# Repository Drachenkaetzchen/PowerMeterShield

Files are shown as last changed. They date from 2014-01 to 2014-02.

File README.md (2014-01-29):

#### **Voltage and Current Meter Shield**

This is a shield to measure voltage (±30V) and current (±10A). It is isolated, so you can hook it up either polarity and even measure negative voltages.

#### **Usage Ideas**
- Combine this shield with an SD card shield to create a data-logging multimeter.
- Combine this shield with a WiFi-Shield to log data to the internet.
- Use the WiFi shield with a solar panel to measure how much power you harvest
- Measure the power consumption of your QuadCopter during flight

#### **Theory of Operation**

Voltage is measured using the THS4521 differential amplifier by converting a bipolar single-ended voltage into a differential voltage, which is fed into the ADC.

Current is measured via the 5mΩ shunt resistor and amplified using the INA170 high-side current shunt monitor. It is converted into a voltage and fed into the ADC.  A 1.024V reference is used to level shift the signal for the ADC so that we can measure negative currents as well (negative range: 0-1.024V and positive range 1.024V to 2.048V).

The ADC used is a MCP3426, which supports up to 16 bits of resolution and an integrated gain amplifier (1x, 2x, 4x and 8x), so if you don't need the full input range of ±30V, you can measure smaller voltages with higher resolutions. The ADC is controlled via I²C.

The ADUM1250 isolates the I²C communications and a 5V DC to DC converter isolates the power rails for the shield.

#### **Specifications**
- Voltage Measurements from -30V to +30V
- Current Measurement from -10A to +10A
- Resolution is 12, 14 or 16 bits. This affects the sample rate (Samples per Second or SPS). 15 SPS at 16 Bits, 60 SPS at 14 Bits and 240 SPS at 12 Bits.
- Digital Gain control of 1x, 2x, 4x or 8x gain
- Input Impedance: >10MΩ
- Burden Voltage: 5mV/A
- Resolution for Voltage Measurements at 16 bit: 4mV at 1x gain (±30V), 2mV at 2x gain (±15V), 1mV at 4x gain (±7.5V) and 0.5mV at 8x gain (±3.75V)
- Resolution for Current Measurements at 16 bit: 1.2mA at 1x gain (±10A), 0.6mA at 2x gain (±5A), 0.3mA at 4x gain (±2.5A) and 0.15mA at 8x gain (±1.25A)
- Works out of the box with all Arduino platforms that feature VREF, SDA and SCL pins. For older Arduino platforms, you may wire VREF to +5V and SDA/SCL to A4/A5 pins.

#### **Project History**

I have built a [solar powered router](http://felicitus.org/solarwind/) for which I have designed a voltage and current measurement board. The voltage and current meter shield evolved from that monitoring board.

I have taken great care to make this shield relatively safe; it doesn't matter which way you connect the measurement inputs - your Arduino will survive due to the isolation (unless you exceed the specified ±30V ±10A input ranges).

#### **License**

This board is licensed under the CERN OHL v1.2.

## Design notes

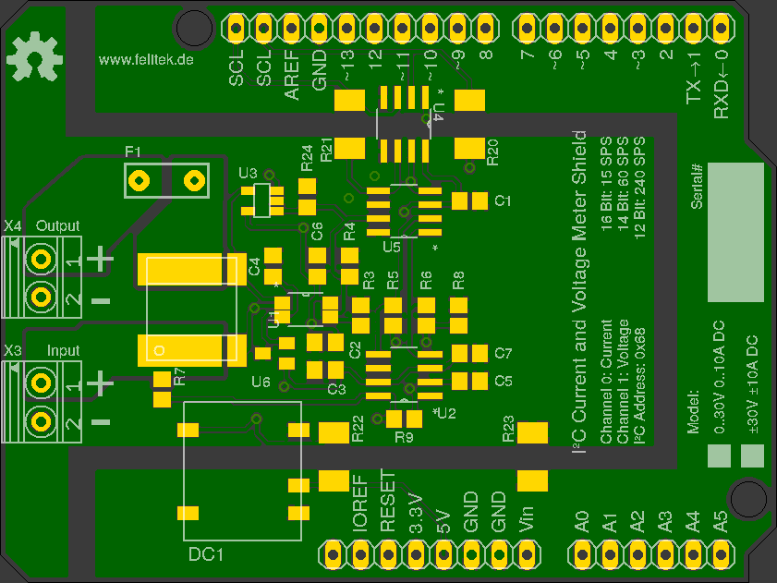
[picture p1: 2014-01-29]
PowerMeterShield_top.png

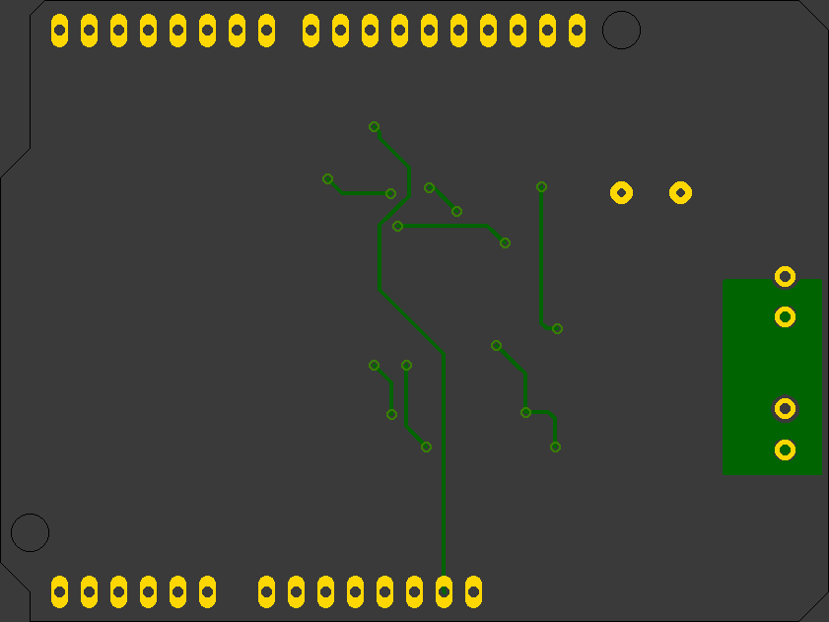
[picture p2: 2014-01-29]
PowerMeterShield_bot.png

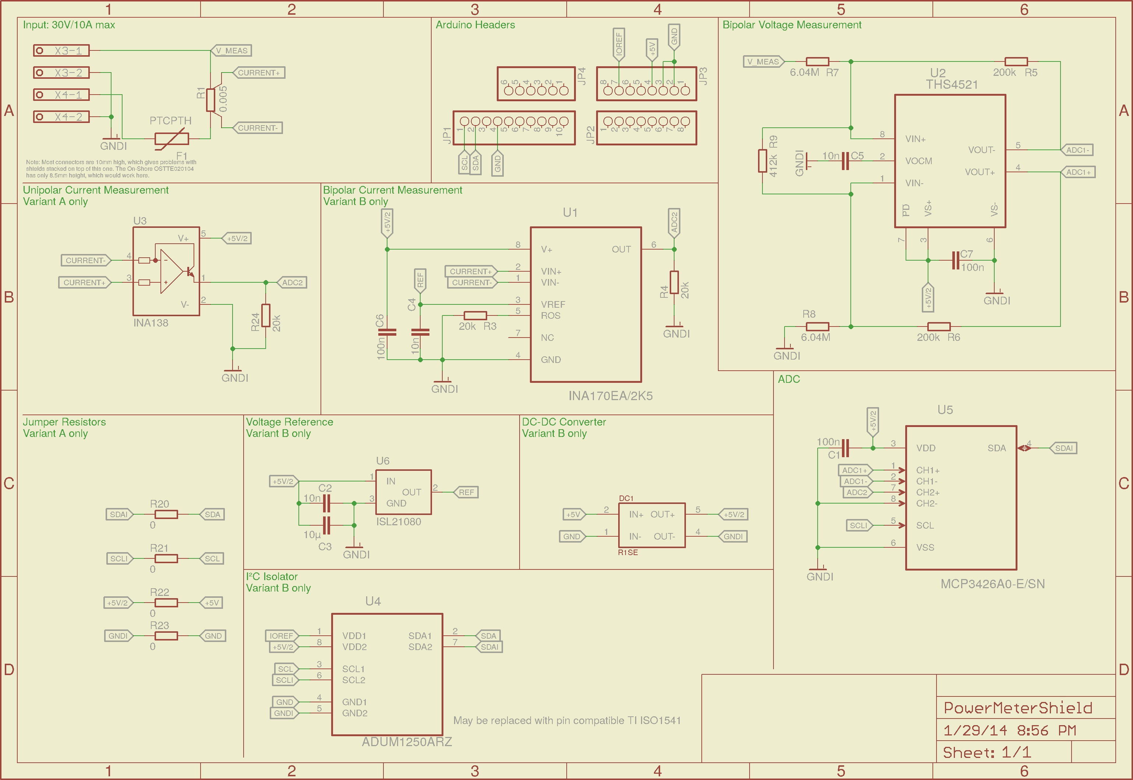
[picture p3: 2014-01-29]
PowerMeterShield_sheet1.png

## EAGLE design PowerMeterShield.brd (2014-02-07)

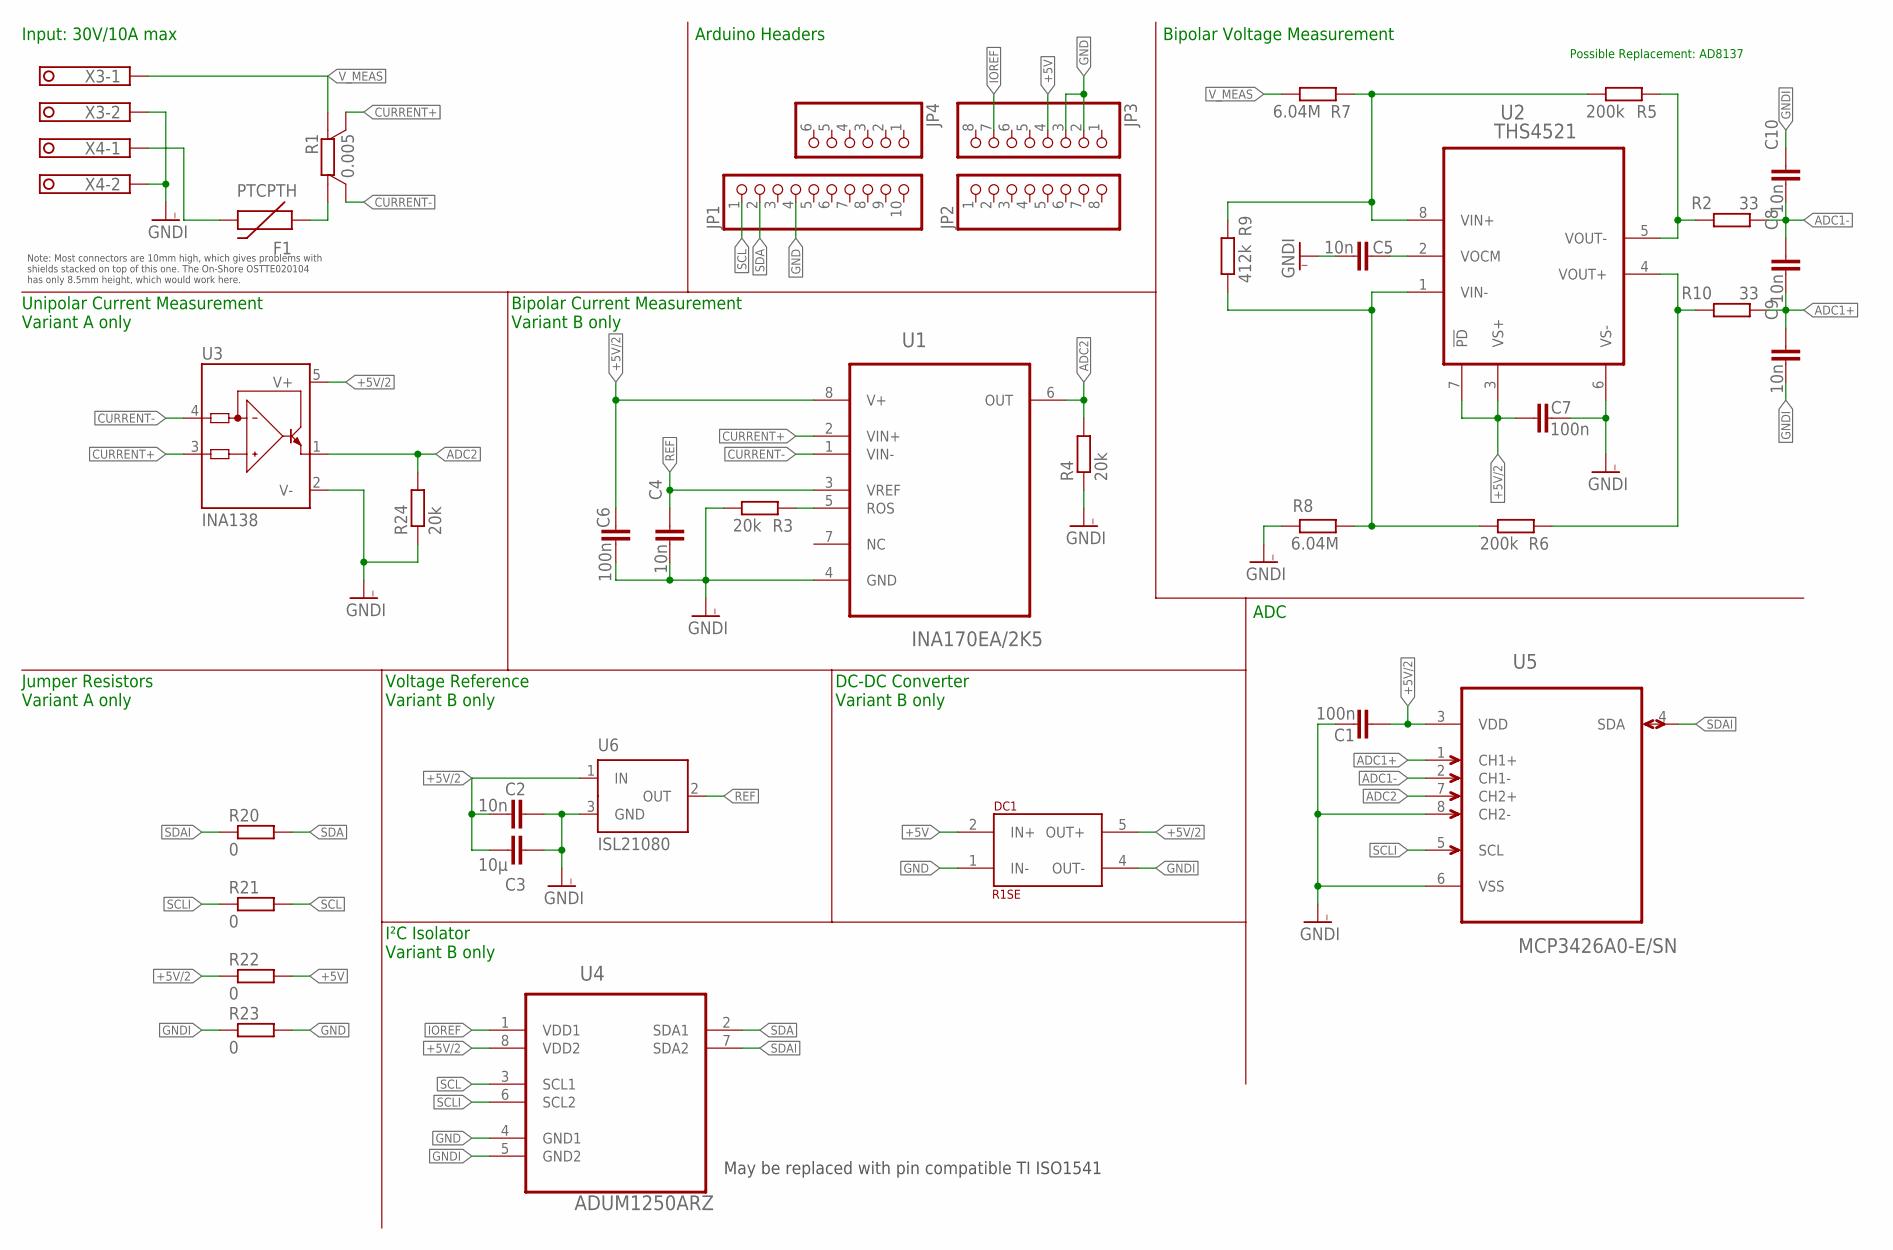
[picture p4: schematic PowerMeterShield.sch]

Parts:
C1, C6, C7: 100n; C0805
C2, C4, C5, C8, C9, C10: 10n; C0805
C3: 10µ; C0805
DC1: R1SE
F1: PTCPTH; PTC
JP1: PINHD-1X10; 1X10
JP2, JP3: PINHD-1X8; 1X08
JP4: PINHD-1X6; 1X06
R1: 0.005; CSM3637M
R2, R10: 33; R0805
R3, R4, R24: 20k; R0805
R5, R6: 200k; R0805
R7, R8: 6.04M; R0805
R9: 412k; R0805
R20, R21, R22, R23: 0; R2010
U1: INA170EA/2K5; SOP65P490X110-8N
U2: THS4521; SOIC127P600X175-8N
U3: INA138; SOT23-5
U4: ADUM1250ARZ; SOIC127P600X175-8N
U5: MCP3426A0-E/SN; SOIC127P600X175-8N
U6: ISL21080; SOT23
X3, X4: 1751248

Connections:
+5V: DC1.2 (IN+), JP3.4, R22.2
+5V/2: C1.1, C2.1, C3.1, C6.1, C7.1, DC1.5 (OUT+), R22.1, U1.8 (V+), U2.3 (VS+), U2.7 (!PD), U3.5 (V+), U4.8 (VDD2), U5.3 (VDD), U6.1 (IN)
ADC1+: C8.1, C9.2, R10.1, U5.1 (CH1+)
ADC1+_OLD: R6.2, R10.2, U2.4 (VOUT+)
ADC1-: C8.2, C10.1, R2.1, U5.2 (CH1-)
ADC1-_OLD: R2.2, R5.2, U2.5 (VOUT-)
ADC2: R4.2, R24.2, U1.6 (OUT), U3.1 (OUT), U5.7 (CH2+)
CURRENT+: R1.S2, U1.2 (VIN+), U3.3 (IN+)
CURRENT-: R1.S1, U1.1 (VIN-), U3.4 (IN-)
GND: DC1.1 (IN-), JP1.4, JP3.2, JP3.3, R23.2, U4.4 (GND1)
GNDI: C1.2, C2.2, C3.2, C4.1, C5.1, C6.2, C7.2, C9.1, C10.2, DC1.4 (OUT-), R3.1, R4.1, R8.1, R23.1, R24.1, U1.4 (GND), U2.6 (VS-), U3.2 (V-), U4.5 (GND2), U5.6 (VSS), U5.8 (CH2-), U6.3 (GND), X3.2, X4.2
IOREF: JP3.7, U4.1 (VDD1)
unnamed: C5.2, U2.2 (VOCM)
unnamed: R5.1, R7.2, R9.2, U2.8 (VIN+)
unnamed: F1.P$1 (1), R1.I1
unnamed: R3.2, U1.5 (ROS)
unnamed: R6.1, R8.2, R9.1, U2.1 (VIN-)
REF: C4.2, U1.3 (VREF), U6.2 (OUT)
SCL: JP1.1, R21.2, U4.3 (SCL1)
SCLI: R21.1, U4.6 (SCL2), U5.5 (SCL)
SDA: JP1.2, R20.2, U4.2 (SDA1)
SDAI: R20.1, U4.7 (SDA2), U5.4 (SDA)
VIN_MEAS: F1.P$2 (2), X4.1
V_MEAS: R1.I2, R7.1, X3.1

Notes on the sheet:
Input: 30V/10A max
Voltage Reference Variant B only
DC-DC Converter Variant B only
Arduino Headers
ADC
I²C Isolator Variant B only
Bipolar Voltage Measurement
Bipolar Current Measurement Variant B only
Unipolar Current Measurement Variant A only
Jumper Resistors Variant A only
Note: Most connectors are 10mm high, which gives problems with shields stacked on top of this one. The On-Shore OSTTE020104 has only 8.5mm height, which would work here.
May be replaced with pin compatible TI ISO1541
Possible Replacement: AD8137

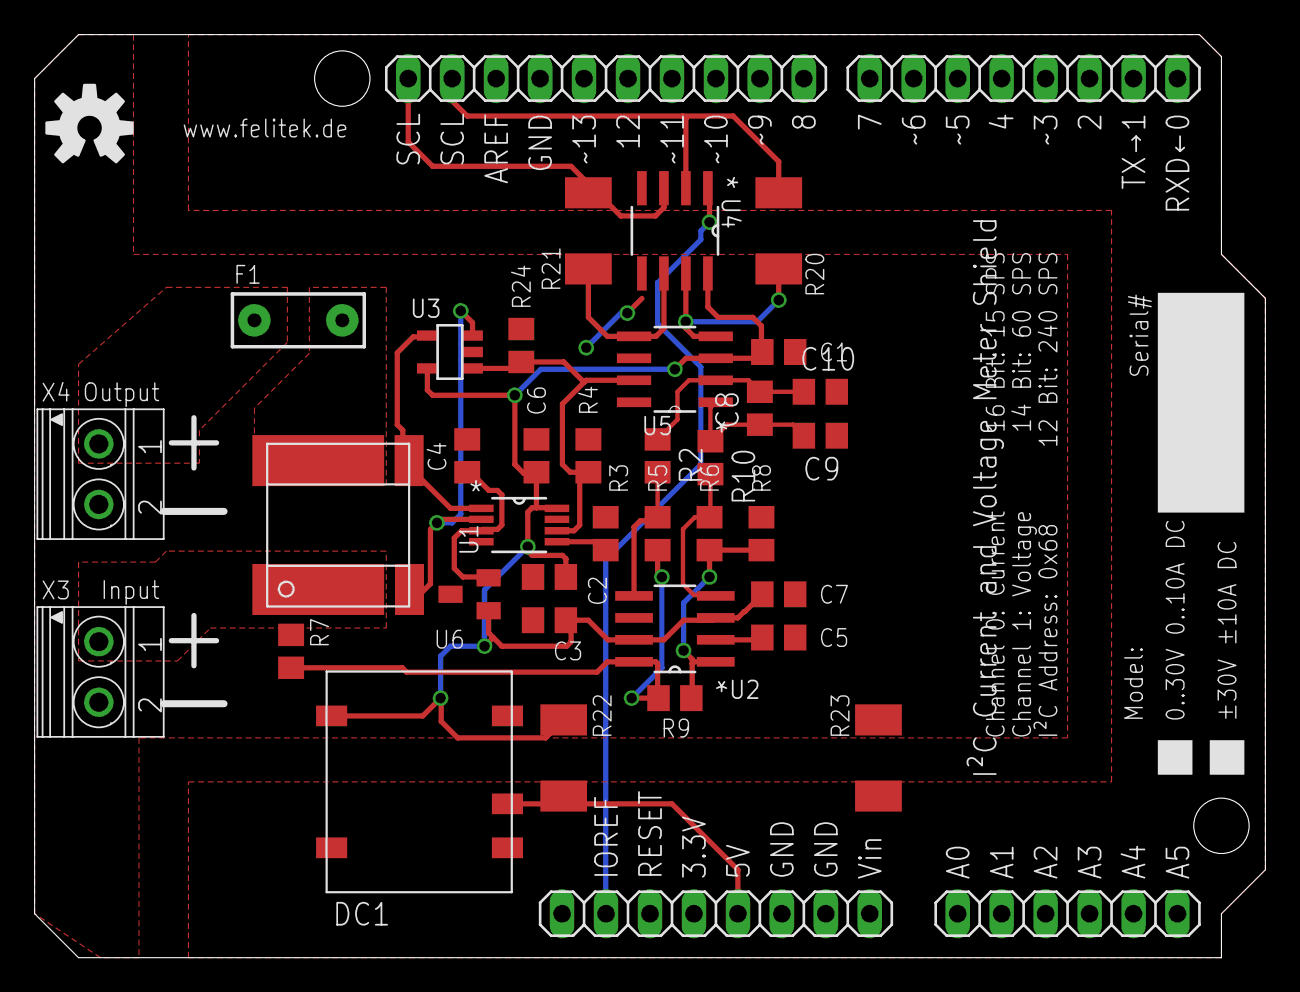
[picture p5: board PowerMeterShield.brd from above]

Board: 2 copper layers, 71.1 x 53.3 mm, 40 parts (0 on the bottom side), 24 nets.

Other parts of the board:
U$1: OSHW-LOGO-M

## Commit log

2013-08-20 Added DC-DC converter to isolate circuit; still missing optocouplers and differential voltage measurement
    [PowerMeterShield.brd, PowerMeterShield.sch]
2013-08-21 Added I²C isolation
    [PowerMeterShield.brd, PowerMeterShield.sch]
2013-08-21 Added creepage distance of about 3mm for a bit of safety™
    [PowerMeterShield.brd, PowerMeterShield.sch]
2013-08-22 Finalized design, made PCB larger in order to compensate for heigher components than the headers, so users can stack other shields on top of ours (hopefully).
    [PowerMeterShield.brd, PowerMeterShield.sch]
2013-08-29 Added readme, added TME for the ADUM1250 isolator
    [PowerMeterShield.brd]
2013-08-30 Added port names to silkscreen, added I²C pullups for the internal I²C bus
    [PowerMeterShield.brd, PowerMeterShield.sch]
2013-08-30 Added use cases to the README, added mains warning
    [PowerMeterShield.brd]
2014-01-23 Updated to a modified design for differential voltage measurement
    [PowerMeterShield.brd, PowerMeterShield.sch]
2014-01-23 Added domain name + descriptions for the functional schematic blocks
    [PowerMeterShield.brd, PowerMeterShield.sch]
2014-01-23 Added functional block descriptions + url on board
    [PowerMeterShield.brd, PowerMeterShield.sch]
2014-01-29 Added non-isolated variant
    [PowerMeterShield.brd, PowerMeterShield.sch]
2014-01-29 Moved logo and website a bit towards the top to align nicely with the isolation
    [PowerMeterShield.brd]
2014-01-29 More fine-adjustments to be symmetric with the isolation planes
    [PowerMeterShield.brd]
2014-01-29 Added device address to silkscreen
    [PowerMeterShield.brd]
2014-01-29 Fixed trace width, added polyfuse
    [PowerMeterShield.brd]
2014-01-29 Removed obsolete GND via
    [PowerMeterShield.brd]
2014-01-29 Fixed fuse designator, misc silkscreen fixes
    [PowerMeterShield.brd, PowerMeterShield.sch]
2014-01-29 In/Out Sockets conflict with some Arduino's USB/Power jacks, added keepout regions and moved the jacks Reworked the traces from the inputs/outputs to be polygons, thanks moemoe!
    [PowerMeterShield.brd]
2014-01-29 Made "Isolate" for the trace-replacement polygons higher
    [PowerMeterShield.brd]
2014-01-29 Added SMD DC-DC converter to match height of the shield headers (old one was 10mm high, new one is only 6.3mm high) Added silkscreen for the arduino headers
    [PowerMeterShield.brd, PowerMeterShield.sch]
2014-01-29 Removed double A5 silkscreen Fixed size for the + signs
    [PowerMeterShield.brd]
2014-01-29 Adjusted R20-R23 positions
    [PowerMeterShield.brd]
2014-01-29 Fixed DC-DC converter footprint
    [PowerMeterShield.brd, PowerMeterShield.sch]
2014-01-29 Configured minimum clearance of 15mil for the inputs
    [PowerMeterShield.brd, PowerMeterShield.sch]
2014-01-29 Added prices + order codes
    [PowerMeterShield.brd, PowerMeterShield.sch]
2014-02-07 Added experimental serial line resistors and capacitors
    [PowerMeterShield.brd, PowerMeterShield.sch]

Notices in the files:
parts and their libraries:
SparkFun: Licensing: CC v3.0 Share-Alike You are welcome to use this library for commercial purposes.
